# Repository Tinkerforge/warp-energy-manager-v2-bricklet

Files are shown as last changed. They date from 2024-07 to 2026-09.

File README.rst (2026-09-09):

WARP Energy Manager Bricklet 2.0
================================

**This Bricklet is currently in development.**

This repository contains the firmware source code and the hardware design
files. The documentation generator configs can be found at
https://github.com/Tinkerforge/generators

.. BEGIN WARP REPOSITORIES (managed block, generated from esp32-firmware/repo_overview.rst - do not edit by hand, run update_repo_overview.py instead)

WARP Repositories
-----------------

This is an overview of all repositories that make up the WARP Charger and
WARP Energy Manager ecosystem.

Please report **any** issue concerning WARP hard- or software in the
`esp32-firmware`_ repository, no matter which repository it originates from.

Software
~~~~~~~~

- `esp32-firmware`_ - Source code of the ESP32 firmware shared between all WARP Chargers and Energy Managers

Libraries used by the firmware:

- `tfjson`_ - SAX style JSON serializer and deserializer
- `tfnetwork`_ - Modbus TCP server and client implementation
- `tfocpp`_ - OCPP 1.6 implementation
- `tftools`_ - Miscellaneous tools and helpers

Remote access:

- `esp32-remote-access`_ - Source code of the my.warp-charger.com remote access server

Documentation, tools and integrations:

- `warp-charger`_ - Source code of (docs.)warp-charger.com and the printed manual, released firmwares, datasheets and documents, as well as some tools and hardware design files
- `api.warp-charger.com`_ - Serves APIs that are used by WARP Chargers to obtain relevant public information like day ahead prices
- `vislog.warp-charger.com`_ - Visualizes WARP Charger logs and EVSE debug protocols
- `dbus-warp-charger`_ - Integrates WARP Chargers into a Victron Energy Venus OS device (e.g. Cerbo GX)

WARP Charger Hardware
~~~~~~~~~~~~~~~~~~~~~~

WARP4 Charger
"""""""""""""

*Current charger generation.*

- `warp-esp32-ethernet-v2-brick`_ - Hardware design files of the WARP ESP32 Ethernet Brick 2.0
- `warp-esp32-ethernet-v2-co-bricklet`_ - Firmware source code of the WARP ESP32 Ethernet 2.0 Co Bricklet (co-processor)
- `evse-v4-bricklet`_ - Hardware design files of the EVSE 4.0 Bricklet (firmware shared with the EVSE 2.0 Bricklet)
- `nfc-bricklet`_ - Firmware source code and hardware design files of the NFC Bricklet

WARP3 Charger
"""""""""""""

- `warp-esp32-ethernet-brick`_ - Hardware design files of the WARP ESP32 Ethernet Brick
- `evse-v3-bricklet`_ - Hardware design files of the EVSE 3.0 Bricklet (firmware shared with the EVSE 2.0 Bricklet)
- `nfc-bricklet`_ - Firmware source code and hardware design files of the NFC Bricklet

WARP2 Charger
"""""""""""""

- `esp32-ethernet-brick`_ - Hardware design files of the ESP32 Ethernet Brick
- `evse-v2-bricklet`_ - Firmware source code and hardware design files of the EVSE 2.0 Bricklet
- `nfc-bricklet`_ - Firmware source code and hardware design files of the NFC Bricklet

WARP1 Charger
"""""""""""""

- `esp32-brick`_ - Hardware design files of the ESP32 Brick
- `evse-bricklet`_ - Firmware source code and hardware design files of the EVSE Bricklet
- `rs485-bricklet`_ - Firmware source code and hardware design files of the RS485 Bricklet

WARP Energy Manager Hardware
~~~~~~~~~~~~~~~~~~~~~~~~~~~~~~

WARP Energy Manager 2.0
"""""""""""""""""""""""

*Current energy manager generation.*

- `esp32-ethernet-brick`_ - Hardware design files of the ESP32 Ethernet Brick
- `warp-energy-manager-v2-bricklet`_ - Firmware source code and hardware design files of the WARP Energy Manager 2.0 Bricklet
- `warp-front-panel-bricklet`_ - Firmware source code and hardware design files of the WARP Front Panel Bricklet

WARP Energy Manager 1.0
"""""""""""""""""""""""

- `esp32-ethernet-brick`_ - Hardware design files of the ESP32 Ethernet Brick
- `warp-energy-manager-bricklet`_ - Firmware source code and hardware design files of the WARP Energy Manager Bricklet

Forked/patched projects
~~~~~~~~~~~~~~~~~~~~~~~~~

- `arduino-esp32`_
- `esp32-arduino-libs`_
- `WireGuard-ESP32-Arduino`_

.. Link targets: One definition per repository, keep in sync with the lists above.

.. _esp32-firmware: https://github.com/Tinkerforge/esp32-firmware
.. _tfjson: https://github.com/Tinkerforge/tfjson
.. _tfnetwork: https://github.com/Tinkerforge/tfnetwork
.. _tfocpp: https://github.com/Tinkerforge/tfocpp
.. _tftools: https://github.com/Tinkerforge/tftools
.. _esp32-remote-access: https://github.com/Tinkerforge/esp32-remote-access
.. _warp-charger: https://github.com/Tinkerforge/warp-charger
.. _api.warp-charger.com: https://github.com/Tinkerforge/api.warp-charger.com
.. _vislog.warp-charger.com: https://github.com/Tinkerforge/vislog.warp-charger.com
.. _dbus-warp-charger: https://github.com/Tinkerforge/dbus-warp-charger
.. _warp-esp32-ethernet-v2-brick: https://github.com/Tinkerforge/warp-esp32-ethernet-v2-brick
.. _warp-esp32-ethernet-v2-co-bricklet: https://github.com/Tinkerforge/warp-esp32-ethernet-v2-co-bricklet
.. _evse-v4-bricklet: https://github.com/Tinkerforge/evse-v4-bricklet
.. _nfc-bricklet: https://github.com/Tinkerforge/nfc-bricklet
.. _warp-esp32-ethernet-brick: https://github.com/Tinkerforge/warp-esp32-ethernet-brick
.. _evse-v3-bricklet: https://github.com/Tinkerforge/evse-v3-bricklet
.. _esp32-ethernet-brick: https://github.com/Tinkerforge/esp32-ethernet-brick
.. _evse-v2-bricklet: https://github.com/Tinkerforge/evse-v2-bricklet
.. _esp32-brick: https://github.com/Tinkerforge/esp32-brick
.. _evse-bricklet: https://github.com/Tinkerforge/evse-bricklet
.. _rs485-bricklet: https://github.com/Tinkerforge/rs485-bricklet
.. _warp-energy-manager-v2-bricklet: https://github.com/Tinkerforge/warp-energy-manager-v2-bricklet
.. _warp-front-panel-bricklet: https://github.com/Tinkerforge/warp-front-panel-bricklet
.. _warp-energy-manager-bricklet: https://github.com/Tinkerforge/warp-energy-manager-bricklet
.. _arduino-esp32: https://github.com/Tinkerforge/arduino-esp32
.. _esp32-arduino-libs: https://github.com/Tinkerforge/esp32-arduino-libs
.. _WireGuard-ESP32-Arduino: https://github.com/Tinkerforge/WireGuard-ESP32-Arduino

.. END WARP REPOSITORIES

Repository Content
------------------

software/:
 * examples/: Examples for all supported languages
 * build/: Compiled files
 * src/: Source code of firmware
 * Makefile: Makefile to build project

hardware/:
 * Contains KiCad project files and additionally schematics as PDF

datasheets/:
 * Contains datasheets for sensors and complex ICs that are used

Hardware
--------

The hardware is designed with the open source EDA Suite KiCad
(http://www.kicad.org). Before you are able to open the files,
you have to install the Tinkerforge kicad-libraries
(https://github.com/Tinkerforge/kicad-libraries). You can either clone
them directly in hardware/ or clone them in a separate folder and
symlink them into hardware/
(ln -s kicad_path/kicad-libraries project_path/hardware). After that you
can open the .pro file in hardware/ with KiCad and from there view and
modify the schematics and the PCB layout.

Software
--------

If you want to do your own Brick/Bricklet firmware development we highly
recommend that you use our build environment setup script and read the
tutorial (https://www.tinkerforge.com/en/doc/Tutorials/Tutorial_Build_Environment/Tutorial.html).

To compile the C code we recommend you to install the newest GNU Arm Embedded
Toolchain (https://launchpad.net/gcc-arm-embedded/+download).
You also need to install bricklib2 (https://github.com/Tinkerforge/bricklib2).

You can either clone it directly in software/src/ or clone it in a
separate folder and symlink it into software/src/
(ln -s bricklib_path/bricklib2 project_path/software/src/). Finally make sure to
have CMake installed (http://www.cmake.org/cmake/resources/software.html).

After that you can build the firmware by invoking make in software/.
The firmware (.zbin) can then be found in software/build/ and uploaded
with brickv (click button "Flashing" on start screen).

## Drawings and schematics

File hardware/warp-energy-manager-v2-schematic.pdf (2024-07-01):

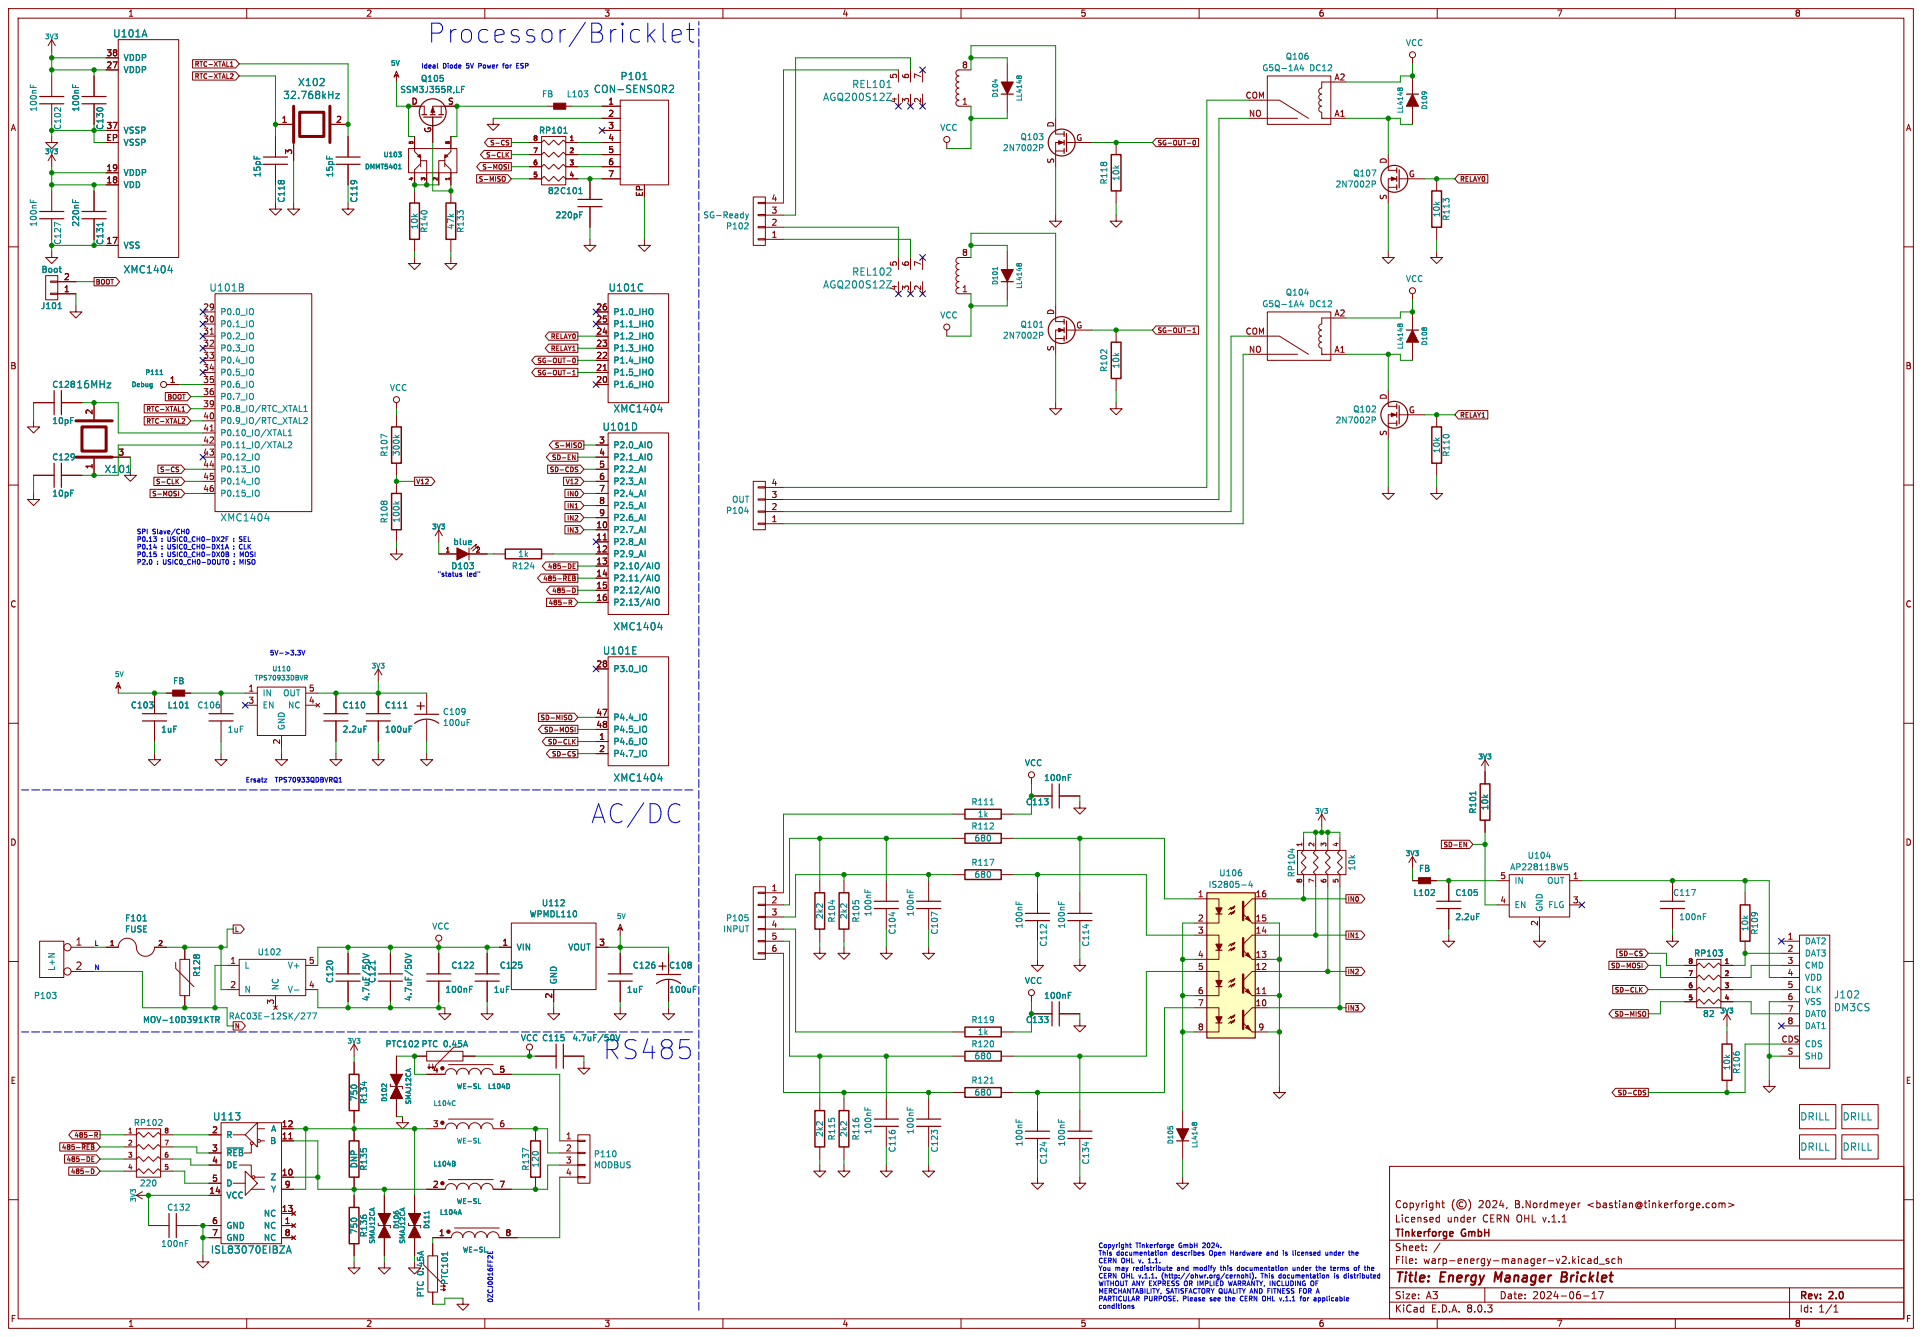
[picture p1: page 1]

VSS 17 VDD 18 VDDP 19 VDDP 27 VSSP 37 VDDP 38 VSSP EPU101A

VCC C116100nF P2.7_AI 10 P2.8_AI 11 P2.9_AI 12 P2.10/AIO 13 P2.11/AIO 14 P2.12/AIO 15 P2.13/AIO 16 P2.0_AIO 3 P2.1_AIO 4 P2.2_AI 5 P2.3_AI 6 P2.4_AI 7 P2.5_AI 8 P2.6_AI 9U101D

Ideal Diode 5V Power for ESP

SD-MOSI
SD-CLK

Id: 1/1 Title: Energy Manager Bricklet File: warp-energy-manager-v2.kicad_sch Sheet: / Tinkerforge GmbH

PARTICULAR PURPOSE. Please see the CERN OHL v.1.1 for applicable
conditions

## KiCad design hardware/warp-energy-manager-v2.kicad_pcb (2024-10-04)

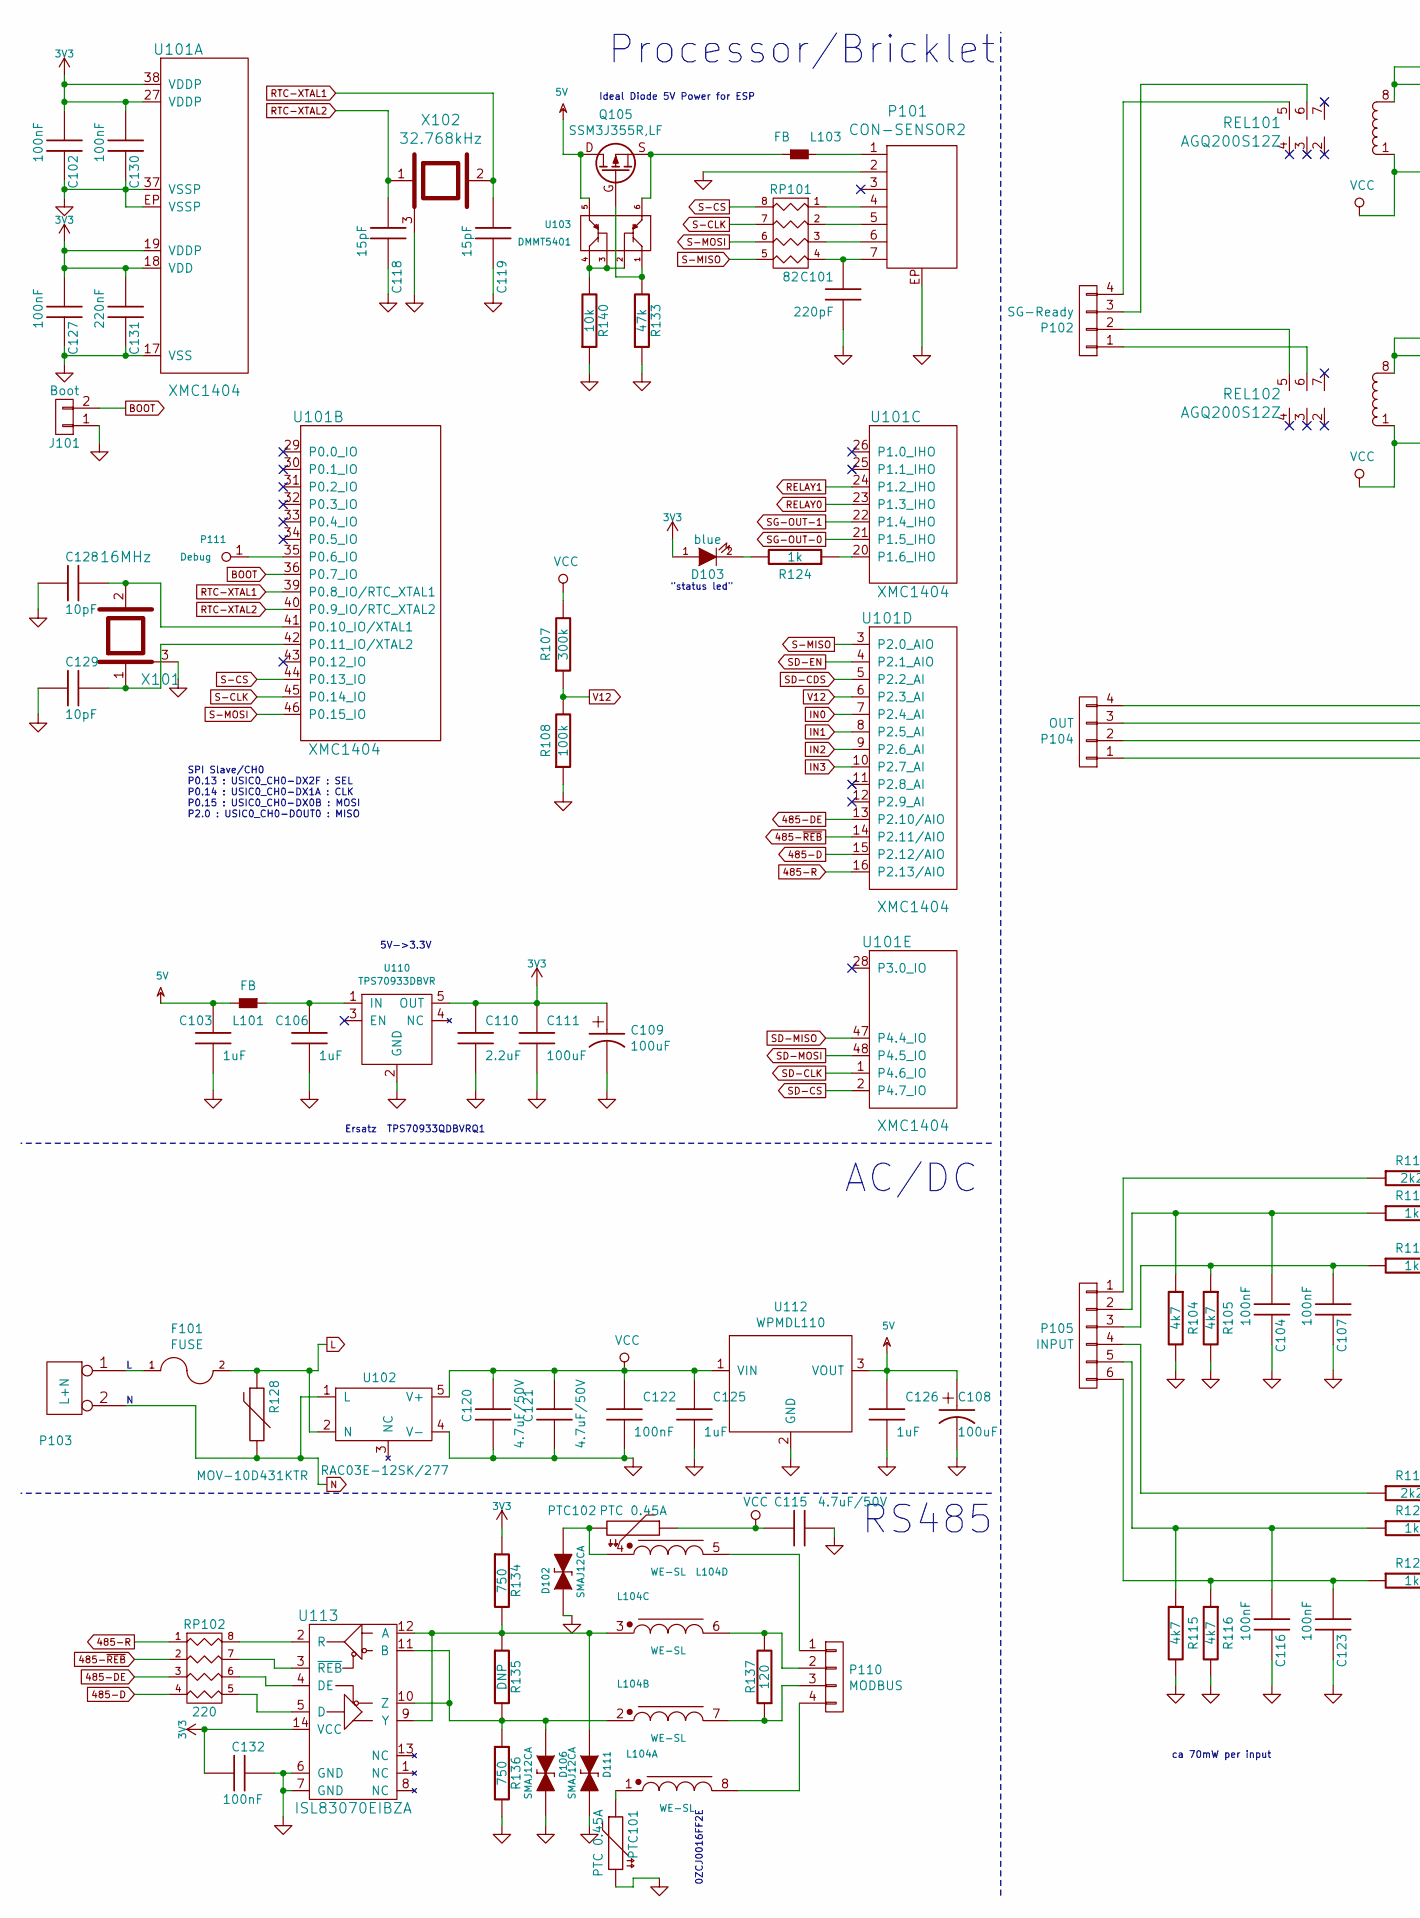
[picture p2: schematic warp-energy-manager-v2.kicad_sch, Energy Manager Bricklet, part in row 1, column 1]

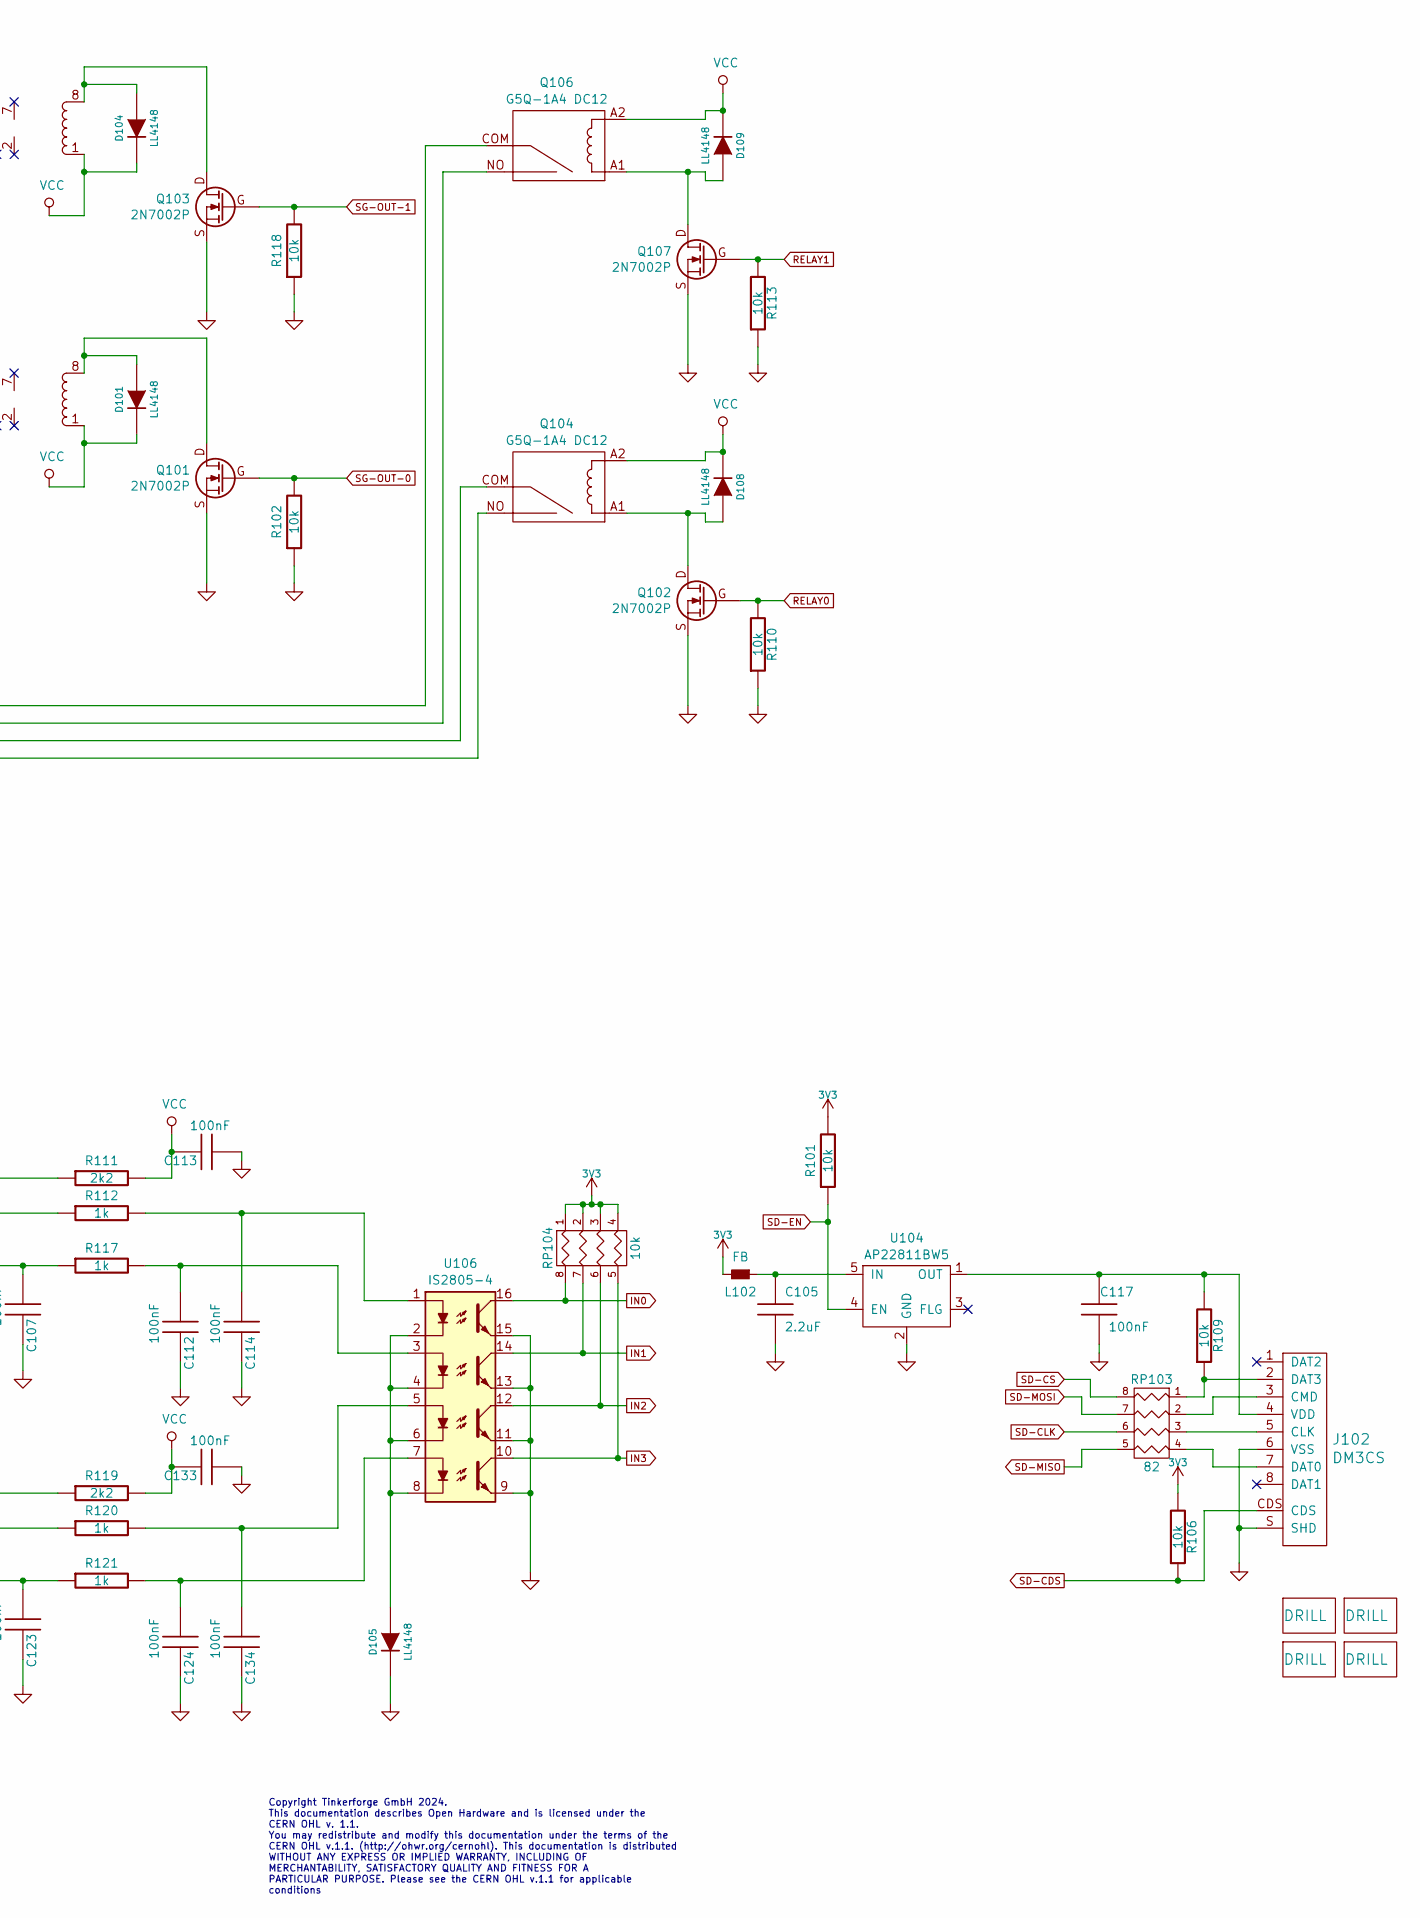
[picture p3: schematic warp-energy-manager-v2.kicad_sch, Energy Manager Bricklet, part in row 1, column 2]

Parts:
A101, A102, A103, A104: DRILL; DRILL_NP_35
C101: 220pF; C0402F
C102, C104, C107, C112, C113, C114, C116, C117, C122, C123, C124, C127, C130, C132, C133, C134: 100nF; C0603F
C103, C106, C125, C126: 1uF; C0603F
C105, C110: 2.2uF; C0603F
C108, C109: 100uF; ELKO_63
C111: 100uF; C1210
C115, C120, C121: 4.7uF/50V; C1206
C118, C119: 15pF; C0603F
C128, C129: 10pF; C0603F
C131: 220nF; C0603F
D101, D104, D105, D108, D109: LL4148; MiniMelf
D102, D106, D111: SMAJ12CA; DO-214AC
D103: blue; D0603F
F101: FUSE; Fuse-Holder-5x20
J101: Boot; SolderJumper
J102: DM3CS; SD-Card-DM3CS
L101, L102, L103: FB; R0603F
L104: WE-SL
P101: CON-SENSOR2; CON-SENSOR2_180
P102: SG-Ready; OQ_4P
P103: L+N; OQ_2P_5mm_230V
P104: OUT; OQ_4P_5mm_230V
P105: INPUT; OQ_6P
P110: MODBUS; OQ_4P
P111: Debug; TSTP_STL
PTC101, PTC102: PTC 0.45A; R1206E
Q101, Q102, Q103, Q107: 2N7002P; SOT23GDS
Q104, Q106: G5Q-1A4 DC12; G5Q-1A
Q105: SSM3J355R,LF; SOT23GDS
R101, R102, R106, R109, R110, R113, R118, R140: 10k; R0603F
R104, R105, R115, R116: 4k7; R0805E
R107: 300k; R0603F
R108: 100k; R0603F
R111, R119: 2k2; R1206E
R112, R117, R120, R121: 1k; R0805E
R124: 1k; R0603F
R128: MOV-10D431KTR; VAR_10mm
R133: 47k; R0603F
R134, R136: 750; R0603F
R135: DNP; R0603F
R137: 120; R0805E
REL101, REL102: AGQ200S12Z; AGQ2X0
RP101, RP103: 82; 4X0402
RP102: 220; 0603X4
RP104: 10k; 4X0603
U101: XMC1404; QFN48-EP2
U102: RAC03E-12SK/277; RAC03E-K277
U103: DMMT5401; SOT26
U104: AP22811BW5; SOT25
U106: IS2805-4; SOIC16_44
U110: TPS70933DBVR; SOT23-5
U112: WPMDL110
U113: ISL83070EIBZA; SOIC-14_3.9x8.7mm_Pitch1.27mm
X101: 16MHz; CRYSTAL_3225
X102: 32.768kHz; AB26TRQ

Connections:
3V3: C102.1, C109.1, C110.1, C111.1, C127.1, C130.1, C131.1, C132.2, D103.1 (A), L102.2, R101.2, R106.2, R134.1, RP104.1, RP104.2, RP104.3, RP104.4, U101.18 (VDD), U101.19 (VDDP), U101.27 (VDDP), U101.38 (VDDP), U110.5 (OUT), U113.14 (VCC)
5V: C103.1, C108.1, C126.1, L101.2, Q105.D, U103.5, U112.3 (VOUT)
485-D: RP102.4, U101.15 (P2.12/AIO)
485-DE: RP102.3, U101.13 (P2.10/AIO)
485-R: RP102.1, U101.16 (P2.13/AIO)
485-~REB: RP102.2, U101.14 (P2.11/AIO)
BOOT: J101.2, U101.36 (P0.7_IO)
GND: C101.2, C102.2, C103.2, C104.2, C105.2, C106.2, C107.2, C108.2, C109.2, C110.2, C111.2, C112.2, C113.1, C114.2, C115.1, C116.2, C117.2, C118.1, C119.1, C120.2, C121.2, C122.2, C123.2, C124.2, C125.2, C126.2, C127.2, C128.2, C129.2, C130.2, C131.2, C132.1, C133.1, C134.2, D102.1 (A), D105.2 (K), D106.2 (K), D111.2 (K), J101.1, J102.6 (VSS), J102.S (SHD), P101.2, P101.EP, PTC101.2, Q101.S, Q102.S, Q103.S, Q107.S, R102.1, R104.2, R105.2, R108.1, R110.1, R113.1, R115.2, R116.2, R118.1, R133.1, R136.2, R140.1, U101.17 (VSS), U101.37 (VSSP), U101.EP (VSSP), U102.4 (V-), U104.2 (GND), U106.9, U106.11, U106.13, U106.15, U110.2 (GND), U112.2 (GND), U113.6 (GND), U113.7 (GND), X101.3, X102.3
IN0: RP104.8 (R1), U101.7 (P2.4_AI), U106.16
IN1: RP104.7 (R2), U101.8 (P2.5_AI), U106.14
IN2: RP104.6 (R3), U101.9 (P2.6_AI), U106.12
IN3: RP104.5 (R4), U101.10 (P2.7_AI), U106.10
L: F101.2, R128.1, U102.2 (N)
N: P103.2 (PM), R128.2, U102.1 (L)
unnamed: C112.1, R117.2, U106.3
unnamed: C114.1, R112.2, U106.1
unnamed: C124.1, R121.2, U106.7
unnamed: C134.1, R120.2, U106.5
unnamed: D101.1 (A), Q101.D, REL102.8
unnamed: D102.2 (K), L104.4, PTC102.2
unnamed: D103.2 (K), R124.2
unnamed: D104.1 (A), Q103.D, REL101.8
unnamed: D105.1 (A), U106.2, U106.4, U106.6, U106.8
unnamed: D106.1 (A), L104.2, R135.2, R136.1, U113.10 (Z), U113.11 (B)
unnamed: D108.1 (A), Q102.D, Q104.A1
unnamed: D109.1 (A), Q106.A1, Q107.D
unnamed: D111.1 (A), L104.3, R134.2, R135.1, U113.9 (Y), U113.12 (A)
unnamed: J102.5 (CLK), RP103.3
unnamed: J102.3 (CMD), RP103.2
unnamed: J102.7 (DAT0), RP103.4
unnamed: J102.2 (DAT3), R109.1, RP103.1
unnamed: C117.1, J102.4 (VDD), R109.2, U104.1 (OUT)
unnamed: L103.1, Q105.S, U103.6
unnamed: L103.2, P101.1
unnamed: L104.1, PTC101.1
unnamed: P102.1, REL102.6
unnamed: P102.2, REL102.5
unnamed: P102.3, REL101.6
unnamed: P102.4, REL101.5
unnamed: F101.1, P103.1
unnamed: P104.1, Q104.NO
unnamed: P104.2, Q104.COM
unnamed: P104.3, Q106.NO
unnamed: P104.4, Q106.COM
unnamed: P105.1, R111.1
unnamed: C104.1, P105.2, R104.1, R112.1
unnamed: C107.1, P105.3, R105.1, R117.1
unnamed: P105.4, R119.1
unnamed: C116.1, P105.5, R115.1, R120.1
unnamed: C123.1, P105.6, R116.1, R121.1
unnamed: L104.5, P110.1
unnamed: L104.6, P110.2, R137.2
unnamed: L104.7, P110.3, R137.1
unnamed: L104.8, P110.4
unnamed: Q105.G, R133.2, U103.1
unnamed: R140.2, U103.2, U103.3, U103.4
unnamed: P101.4, RP101.1
unnamed: P101.5, RP101.2
unnamed: P101.6, RP101.3
unnamed: C101.1, P101.7, RP101.4
unnamed: RP102.8 (R1), U113.2 (R)
unnamed: RP102.7 (R2), U113.3 (~REB)
unnamed: RP102.6 (R3), U113.4 (DE)
unnamed: RP102.5 (R4), U113.5 (D)
unnamed: P111.1, U101.35 (P0.6_IO)
unnamed: C128.1, U101.41 (P0.10_IO/XTAL1), X101.2
unnamed: C129.1, U101.42 (P0.11_IO/XTAL2), X101.1
unnamed: R124.1, U101.20 (P1.6_IHO)
unnamed: C105.1, L102.1, U104.5 (IN)
unnamed: C106.1, L101.1, U110.1 (IN)
RELAY0: Q102.G, R110.2, U101.23 (P1.3_IHO)
RELAY1: Q107.G, R113.2, U101.24 (P1.2_IHO)
RTC-XTAL1: C119.2, U101.39 (P0.8_IO/RTC_XTAL1), X102.2
RTC-XTAL2: C118.2, U101.40 (P0.9_IO/RTC_XTAL2), X102.1
S-CLK: RP101.7 (R2), U101.45 (P0.14_IO)
S-CS: RP101.8 (R1), U101.44 (P0.13_IO)
S-MISO: RP101.5 (R4), U101.3 (P2.0_AIO)
S-MOSI: RP101.6 (R3), U101.46 (P0.15_IO)
SD-CDS: J102.CDS, R106.1, U101.5 (P2.2_AI)
SD-CLK: RP103.6 (R3), U101.1 (P4.6_IO)
SD-CS: RP103.8 (R1), U101.2 (P4.7_IO)
SD-EN: R101.1, U101.4 (P2.1_AIO), U104.4 (EN)
SD-MISO: RP103.5 (R4), U101.47 (P4.4_IO)
SD-MOSI: RP103.7 (R2), U101.48 (P4.5_IO)
SG-OUT-0: Q101.G, R102.2, U101.21 (P1.5_IHO)
SG-OUT-1: Q103.G, R118.2, U101.22 (P1.4_IHO)
V12: R107.1, R108.2, U101.6 (P2.3_AI)
VCC: C113.2, C115.2, C120.1, C121.1, C122.1, C125.1, C133.2, D101.2 (K), D104.2 (K), D108.2 (K), D109.2 (K), PTC102.1, Q104.A2, Q106.A2, R107.2, R111.2, R119.2, REL101.1, REL102.1, U102.5 (V+), U112.1 (VIN)

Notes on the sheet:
ca 70mW per input
SPI Slave/CH0 P0.13 : USIC0_CH0-DX2F : SEL P0.14 : USIC0_CH0-DX1A : CLK P0.15 : USIC0_CH0-DX0B : MOSI P2.0 : USIC0_CH0-DOUT0 : MISO
Ersatz TPS70933QDBVRQ1
Processor/Bricklet
"status led"
0ZCJ0016FF2E
RS485
5V->3.3V
Copyright Tinkerforge GmbH 2024. This documentation describes Open Hardware and is licensed under the CERN OHL v. 1.1. You may redistribute and modify this documentation under the terms of the CERN OHL v.1.1. (http://ohwr.org/cernohl). This documentation is distributed WITHOUT ANY EXPRESS OR IMPLIE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
AC/DC
Ideal Diode 5V Power for ESP

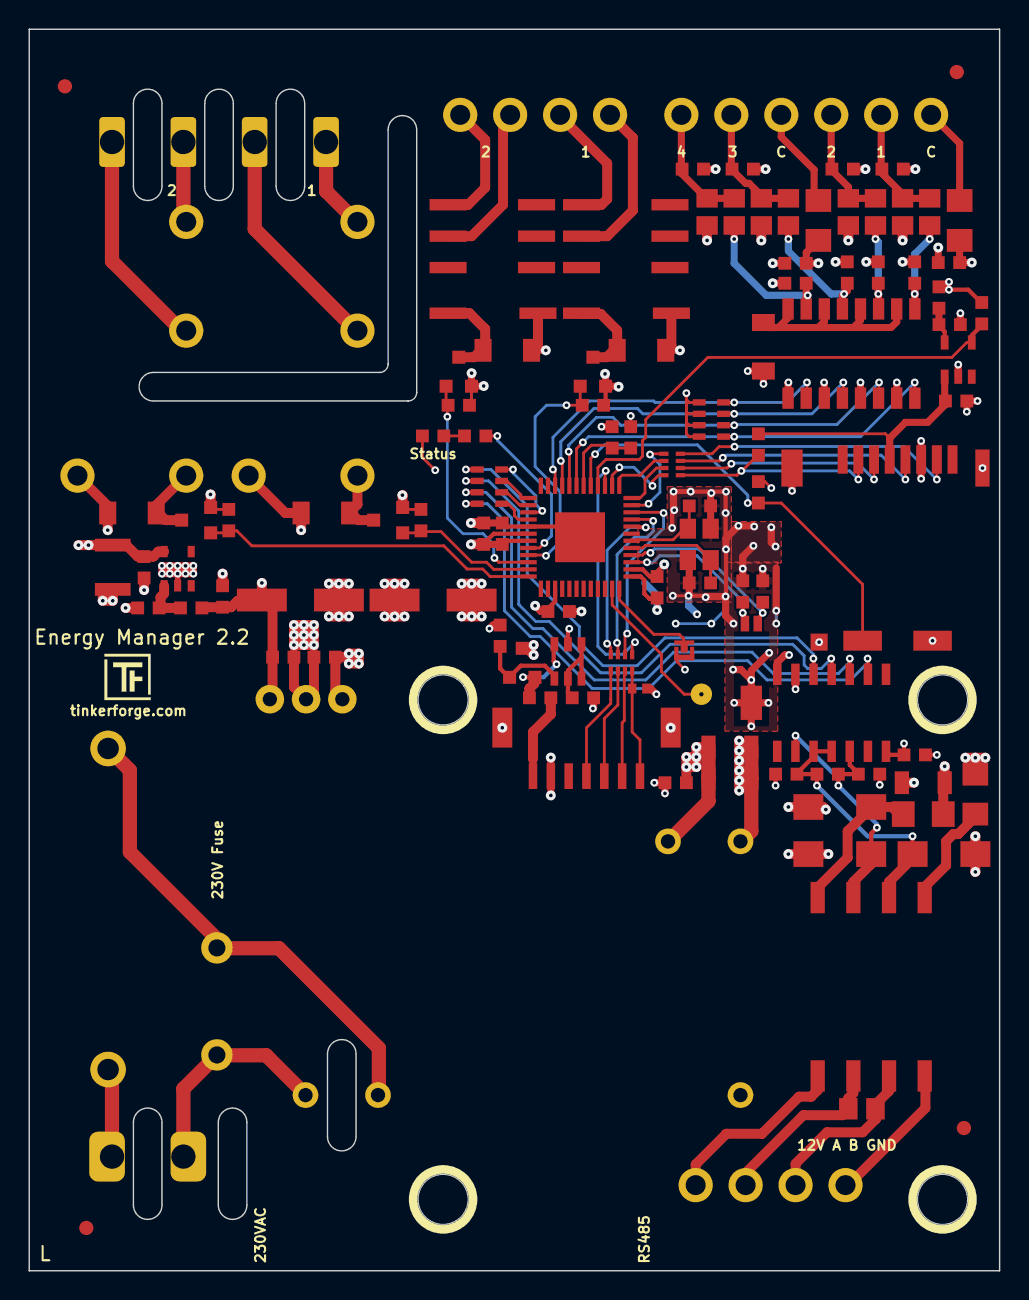
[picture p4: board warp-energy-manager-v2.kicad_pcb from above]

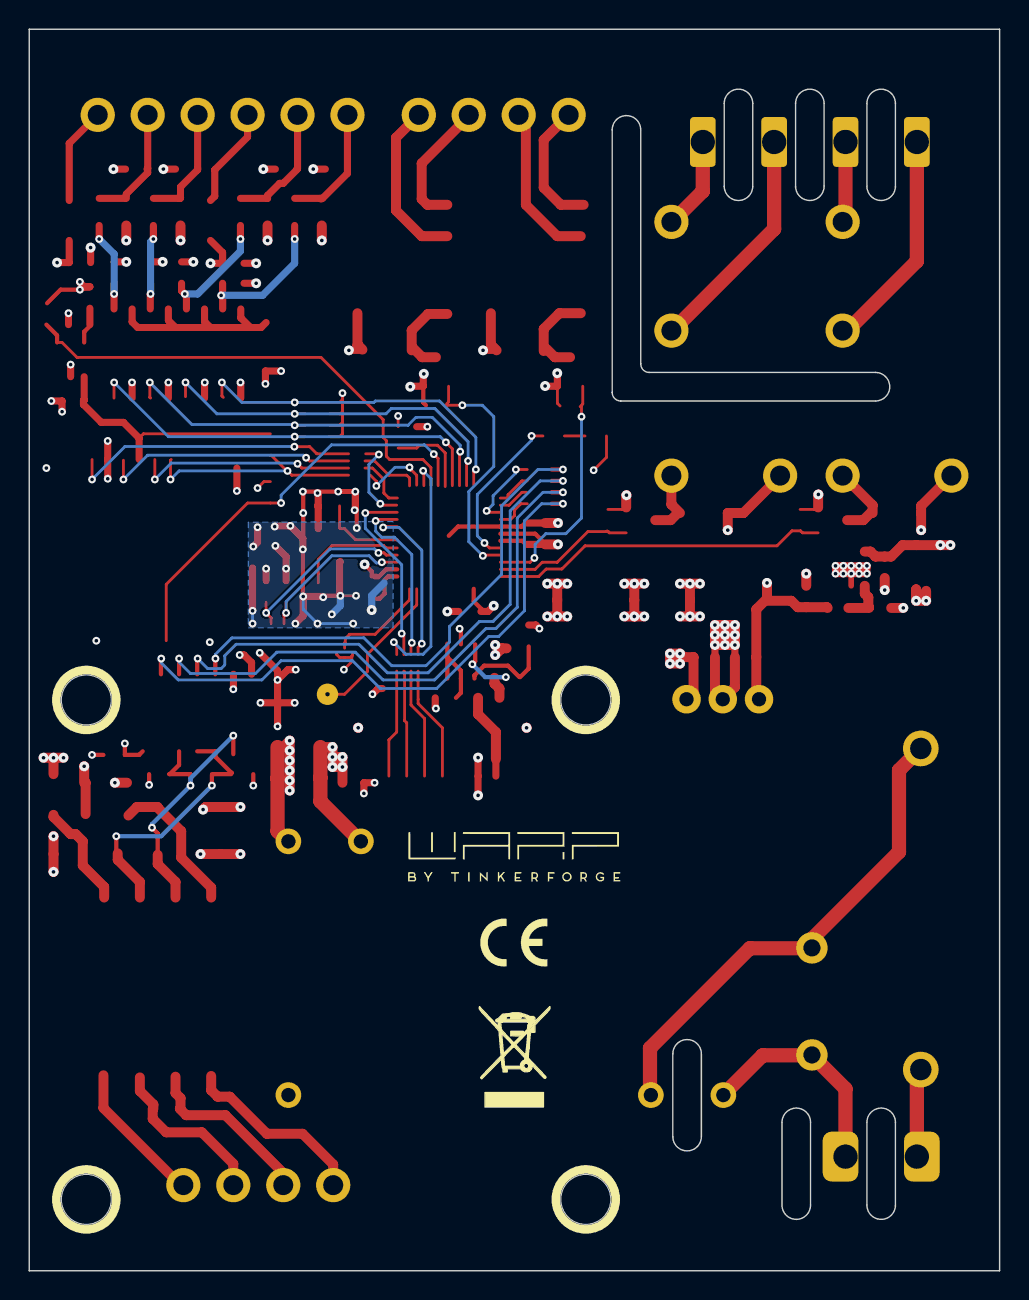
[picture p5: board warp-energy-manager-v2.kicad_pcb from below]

Board: 4 copper layers, 68.0 x 87.0 mm, 119 parts (2 on the bottom side), 88 nets.

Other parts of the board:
Fiducial_Mark: VAL**; Fiducial_Mark
Fiducial_Mark#2, Fiducial_Mark#3, Fiducial_Mark#4: VAL**; Fiducial_Mark
VAL: WEEE_7mm
VAL#2: CE_5mm

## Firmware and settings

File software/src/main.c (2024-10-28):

/* warp-energy-manager-v2-bricklet
 * Copyright (C) 2024 Olaf Lüke <olaf@tinkerforge.com>
 *
 * main.c: Initialization for WARP Energy Manager Bricklet 2.0
 *
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
 * You should have received a copy of the GNU Lesser General Public
 * License along with this library; if not, write to the
 * Free Software Foundation, Inc., 59 Temple Place - Suite 330,
 * Boston, MA 02111-1307, USA.
 */

#include <stdio.h>
#include <stdbool.h>

#include "configs/config.h"

#include "bricklib2/warp/rs485.h"
#include "bricklib2/warp/meter.h"
#include "bricklib2/bootloader/bootloader.h"
#include "bricklib2/hal/system_timer/system_timer.h"
#include "bricklib2/logging/logging.h"
#include "communication.h"

#include "io.h"
#include "voltage.h"
#include "eeprom.h"
#include "date_time.h"
#include "sd.h"
#include "data_storage.h"

int main(void) {
	logging_init();
	logd("Start WARP Energy Manager Bricklet 2.0\n\r");

	communication_init();
	io_init();
	rs485_init();
	meter_init();
	voltage_init();
	eeprom_init();
	date_time_init();
	data_storage_init();
	sd_init();

	while(true) {
		bootloader_tick();
		communication_tick();
		io_tick();
		rs485_tick();
		meter_tick();
		voltage_tick();
		date_time_tick();
		sd_tick();
		data_storage_tick();
	}
}

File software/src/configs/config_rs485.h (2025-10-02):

/* warp-energy-manager-v2-bricklet
 * Copyright (C) 2024 Olaf Lüke <olaf@tinkerforge.com>
 *
 * config_rs485.h: RS485 communication config
 *
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
 * You should have received a copy of the GNU Lesser General Public
 * License along with this library; if not, write to the
 * Free Software Foundation, Inc., 59 Temple Place - Suite 330,
 * Boston, MA 02111-1307, USA.
 */

#ifndef CONFIG_RS485_H
#define CONFIG_RS485_H

#include "xmc_common.h"
#include "xmc_gpio.h"
#include "xmc_uart.h"
#include "xmc_scu.h"

#define RS485_USIC_CHANNEL        USIC1_CH1
#define RS485_USIC                XMC_UART1_CH1

#define RS485_RX_PIN              P2_13
#define RS485_RX_INPUT            XMC_UART_CH_INPUT_RXD // UART input stage DX0
#define RS485_RX_SOURCE           0b011 // DX0D

#define RS485_TX_PIN              P2_12
#define RS485_TX_PIN_AF           (XMC_GPIO_MODE_OUTPUT_PUSH_PULL_ALT7 | P2_12_AF_U1C1_DOUT0)

#define RS485_NRXE_PIN            P2_11
#define RS485_TXE_PIN             P2_10

#define RS485_NRXE_AND_TXE_PORT   XMC_GPIO_PORT2
#define RS485_NRXE_PIN_NUM        11
#define RS485_TXE_PIN_NUM         10

#define RS485_SERVICE_REQUEST_RX  0  // receive
#define RS485_SERVICE_REQUEST_TX  1  // transfer
#define RS485_SERVICE_REQUEST_TFF 4  // transfer frame finished
#define RS485_SERVICE_REQUEST_RXA 5  // alternate receive (parity error)

// Make sure that the priorities are as follows
// RX > TX = TFF
// TFF should never displace TX. TFF is unnecessary if we are in TX IRQ
// TX should never displace TFF. This would be a race condition
// RX interrupt will never be issued if TXE is set. If we are receiving a message,
// TX should never interrupt RX (we would lose data in this case)
// For full-duplex there is no TFF and RX should be higher priority then TX
#define RS485_IRQ_RX              9
#define RS485_IRQ_RX_PRIORITY     2
#define RS485_IRQCTRL_RX          XMC_SCU_IRQCTRL_USIC1_SR0_IRQ9

#define RS485_IRQ_TX              10
#define RS485_IRQ_TX_PRIORITY     3
#define RS485_IRQCTRL_TX          XMC_SCU_IRQCTRL_USIC1_SR1_IRQ10

#define RS485_IRQ_TFF             13
#define RS485_IRQ_TFF_PRIORITY    3
#define RS485_IRQCTRL_TFF         XMC_SCU_IRQCTRL_USIC1_SR4_IRQ13

#define RS485_IRQ_RXA             14
#define RS485_IRQ_RXA_PRIORITY    2
#define RS485_IRQCTRL_RXA         XMC_SCU_IRQCTRL_USIC1_SR5_IRQ14


#define RS485_RX_HANDLER     IRQ_Hdlr_9
#define RS485_RX_FIFO_POS    32
#define RS485_RX_FIFO_LENGTH XMC_USIC_CH_FIFO_SIZE_16WORDS
#define RS485_RX_FIFO_LIMIT  8
#define RS485_TX_HANDLER     IRQ_Hdlr_10
#define RS485_TX_FIFO_POS    48
#define RS485_TX_FIFO_LENGTH XMC_USIC_CH_FIFO_SIZE_16WORDS
#define RS485_TX_FIFO_LIMIT  8
#define RS485_BUFFER_SIZE    (512*2)


#endif

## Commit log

2024-06-13 initial commit of autogenerated bricklet firmware stub
    [cmake_config_custom.txt]
2024-06-17 Remove LED functions (will be in WARP Front Panel Bricklet)
    [communication.h]
2024-06-17 Split output into sg ready and relay output
2024-06-17 first hardware mockup
    [warp-energy-manager-v2.kicad_pcb, warp-energy-manager-v2.kicad_sch]
2024-06-20 routing started
    [warp-energy-manager-v2.kicad_pcb, warp-energy-manager-v2.kicad_sch]
2024-06-20 fix schematic drcs
    [warp-energy-manager-v2.kicad_pcb, warp-energy-manager-v2.kicad_sch]
2024-06-21 fully routed
    [warp-energy-manager-v2.kicad_pcb, warp-energy-manager-v2.kicad_sch]
2024-06-21 all bugs fixed
    [warp-energy-manager-v2.kicad_pcb, warp-energy-manager-v2.kicad_sch]
2024-06-21 prototype version
    [warp-energy-manager-v2.kicad_pcb]
2024-06-24 add 3d models
    [warp-energy-manager-v2.kicad_pcb, warp-energy-manager-v2.kicad_sch]
2024-06-24 add descriptions
    [warp-energy-manager-v2.kicad_pcb]
2024-07-01 add schematic as pdf
2024-07-01 fix relay1 control function
2024-07-17 add version 2.1: fix varistor space, fix status led
    [warp-energy-manager-v2.kicad_pcb, warp-energy-manager-v2.kicad_sch]
2024-07-18 hardware version 2.2 : changed connector overhang by +1,5mm
    [warp-energy-manager-v2.kicad_pcb]
2024-09-02 Move EEPROM and voltage code to bricklib
2024-09-13 change varistor value
    [warp-energy-manager-v2.kicad_pcb, warp-energy-manager-v2.kicad_sch]
2024-09-13 Change default for all relays to low
2024-09-14 Fix LED pin
2024-09-17 Fix configuration for 12V input voltage measurement
    [config_voltage.h]
2024-09-18 Fix order of output pins
    [config_io.h]
2024-10-04 add logos
    [warp-energy-manager-v2.kicad_pcb, warp-energy-manager-v2.kicad_sch]
2025-09-16 Rename MeterRegisterType to use the same name as in esp32 firmware
2025-10-02 Fix -Wextra warnings and add new warning flags introduced in EVSE V2
    [config_rs485.h, config_sdmmc.h]

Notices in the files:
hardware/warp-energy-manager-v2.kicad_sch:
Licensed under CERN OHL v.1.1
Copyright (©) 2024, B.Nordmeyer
